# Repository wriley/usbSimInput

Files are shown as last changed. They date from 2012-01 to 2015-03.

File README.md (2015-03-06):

# usbSimInput

This project is a 128 button USB HID joystick based on an open source USB game controller adapter by Raphaël Assénat.
http://www.raphnet-tech.com/products/nes2usb/

I use it to interface a lot of switches to a flight simulator but you could use it for anything that requires a lot of buttons.

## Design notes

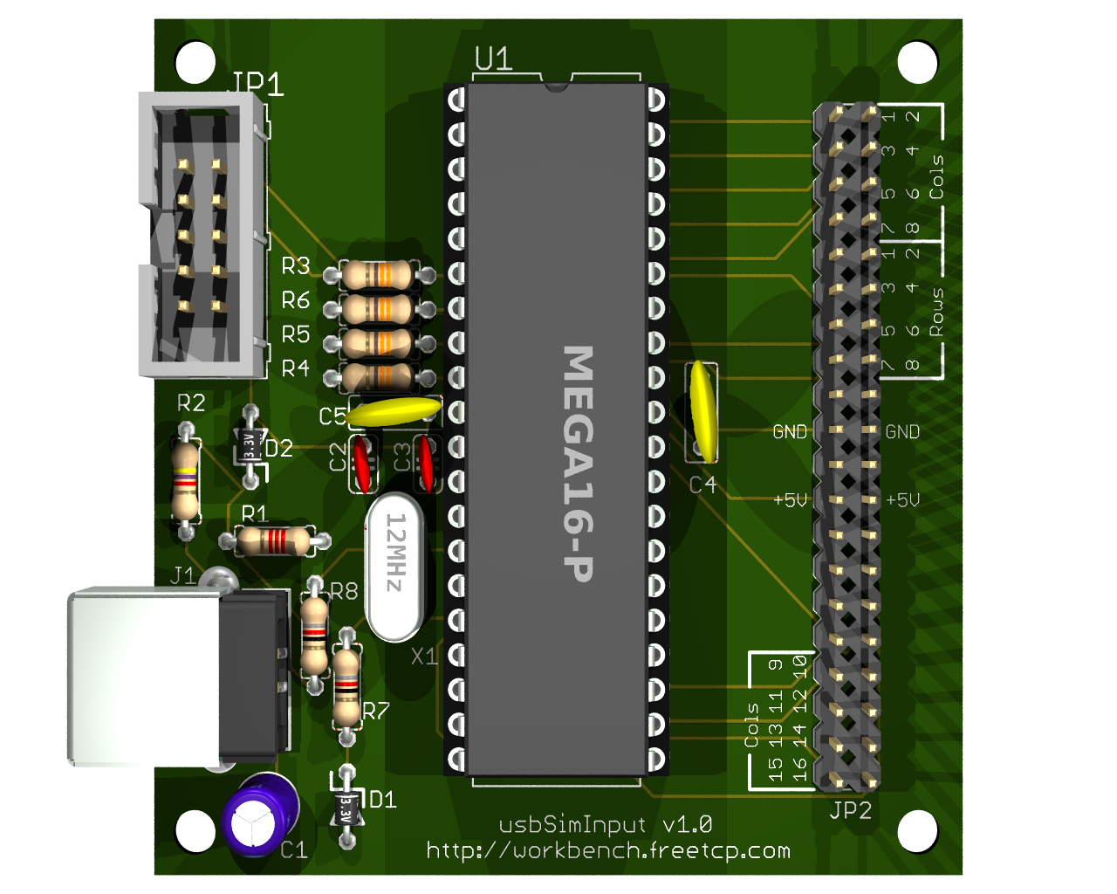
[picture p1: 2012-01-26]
pcb/usbSimInput.bmp

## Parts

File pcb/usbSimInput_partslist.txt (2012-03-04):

Partlist

Exported from usbSimInput.sch at 3/3/2012 2:18:12 PM

EAGLE Version 6.1.0 Copyright (c) 1988-2012 CadSoft

Assembly variant: 

Part     Value          Device          Package      Library  Sheet

C1       10uF           CPOL-USE2.5-5   E2,5-5       rcl      1
C2       15pF           C-US025-024X044 C025-024X044 rcl      1
C3       15pF           C-US025-024X044 C025-024X044 rcl      1
C4       0.1uF          C-US050-025X075 C050-025X075 rcl      1
C5       0.1uF          C-US050-025X075 C050-025X075 rcl      1
D1       3.3V           ZENER-DIODEZD-5 ZDIO-5       diode    1
D2       3.3V           ZENER-DIODEZD-5 ZDIO-5       diode    1
J1                      PN61729-S       PN61729-S    con-berg 1
JP1                     ML10            ML10         con-ml   1
JP2                     MA20-2          MA20-2       con-lstb 1
R1       2K2            R-US_0207/7     0207/7       resistor 1
R2       4K7            R-US_0207/7     0207/7       resistor 1
R3       330            R-US_0207/7     0207/7       resistor 1
R4       330            R-US_0207/7     0207/7       resistor 1
R5       330            R-US_0207/7     0207/7       resistor 1
R6       330            R-US_0207/7     0207/7       resistor 1
R7       82             R-US_0207/7     0207/7       resistor 1
R8       82             R-US_0207/7     0207/7       resistor 1
U1       MEGA16-P       MEGA16-P        DIL40        atmel    1
X1       12MHz          CRYSTALHC49U-V  HC49U-V      crystal  1

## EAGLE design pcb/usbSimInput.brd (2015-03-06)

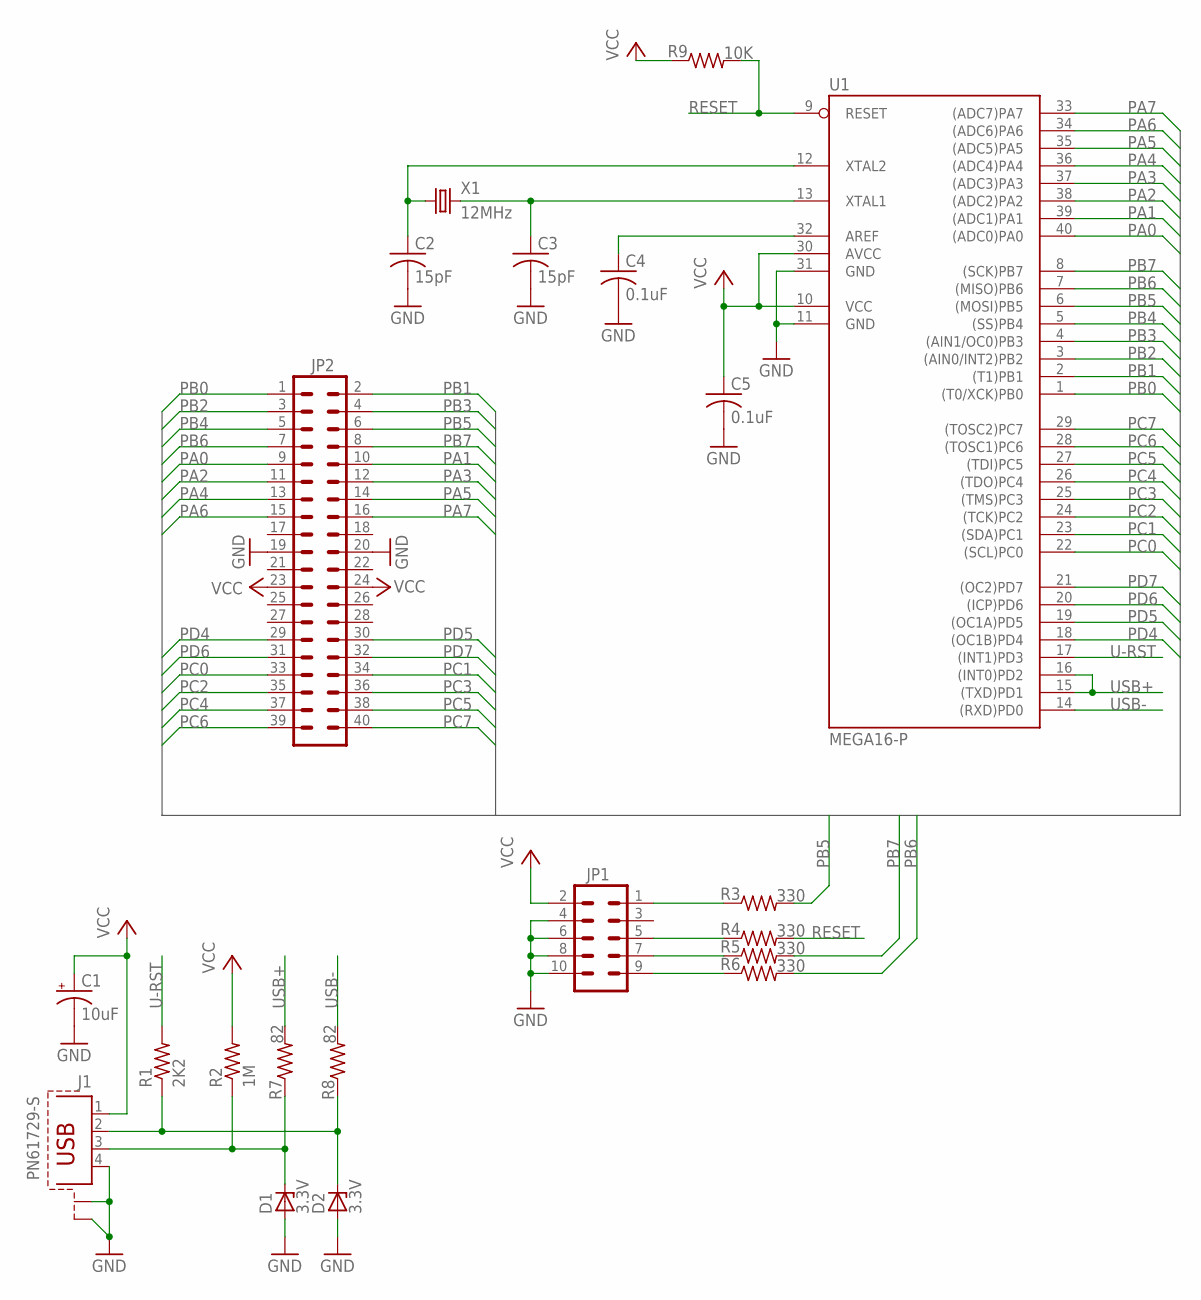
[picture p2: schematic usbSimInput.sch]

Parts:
C1: 10uF; E2,5-5
C2, C3: 15pF; C025-024X044
C4, C5: 0.1uF; C050-025X075
D1, D2: 3.3V; ZDIO-5
J1: PN61729-S
JP1: ML10
JP2: MA20-2
R1: 2K2; 0207/7
R2: 1M; 0207/7
R3, R4, R5, R6: 330; 0207/7
R7, R8: 82; 0207/7
R9: 10K; 0207/7
U1: MEGA16-P; DIL40
X1: 12MHz; HC49U-V

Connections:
GND: C1.-, C2.2, C3.2, C4.2, C5.2, D1.A, D2.A, J1.4, J1.S1, J1.S2, JP1.4, JP1.6, JP1.8, JP1.10, JP2.19, JP2.20, U1.11 (GND), U1.31 (GND)
unnamed: JP1.1, R3.1
unnamed: JP1.5, R4.1
unnamed: JP1.7, R5.1
unnamed: JP1.9, R6.1
unnamed: C3.1, U1.13 (XTAL1), X1.2
unnamed: C2.1, U1.12 (XTAL2), X1.1
unnamed: D2.C, J1.2, R1.1, R8.1
unnamed: C4.1, U1.32 (AREF)
unnamed: D1.C, J1.3, R2.1, R7.1
PA0: JP2.9, U1.40 ((ADC0)PA0)
PA1: JP2.10, U1.39 ((ADC1)PA1)
PA2: JP2.11, U1.38 ((ADC2)PA2)
PA3: JP2.12, U1.37 ((ADC3)PA3)
PA4: JP2.13, U1.36 ((ADC4)PA4)
PA5: JP2.14, U1.35 ((ADC5)PA5)
PA6: JP2.15, U1.34 ((ADC6)PA6)
PA7: JP2.16, U1.33 ((ADC7)PA7)
PB0: JP2.1, U1.1 ((T0/XCK)PB0)
PB1: JP2.2, U1.2 ((T1)PB1)
PB2: JP2.3, U1.3 ((AIN0/INT2)PB2)
PB3: JP2.4, U1.4 ((AIN1/OC0)PB3)
PB4: JP2.5, U1.5 ((SS)PB4)
PB5: JP2.6, R3.2, U1.6 ((MOSI)PB5)
PB6: JP2.7, R6.2, U1.7 ((MISO)PB6)
PB7: JP2.8, R5.2, U1.8 ((SCK)PB7)
PC0: JP2.33, U1.22 ((SCL)PC0)
PC1: JP2.34, U1.23 ((SDA)PC1)
PC2: JP2.35, U1.24 ((TCK)PC2)
PC3: JP2.36, U1.25 ((TMS)PC3)
PC4: JP2.37, U1.26 ((TDO)PC4)
PC5: JP2.38, U1.27 ((TDI)PC5)
PC6: JP2.39, U1.28 ((TOSC1)PC6)
PC7: JP2.40, U1.29 ((TOSC2)PC7)
PD4: JP2.29, U1.18 ((OC1B)PD4)
PD5: JP2.30, U1.19 ((OC1A)PD5)
PD6: JP2.31, U1.20 ((ICP)PD6)
PD7: JP2.32, U1.21 ((OC2)PD7)
RESET: R4.2, R9.2, U1.9 (RESET)
U-RST: R1.2, U1.17 ((INT1)PD3)
USB+: R7.2, U1.15 ((TXD)PD1), U1.16 ((INT0)PD2)
USB-: R8.2, U1.14 ((RXD)PD0)
VCC: C1.+, C5.1, J1.1, JP1.2, JP2.23, JP2.24, R2.2, R9.1, U1.10 (VCC), U1.30 (AVCC)

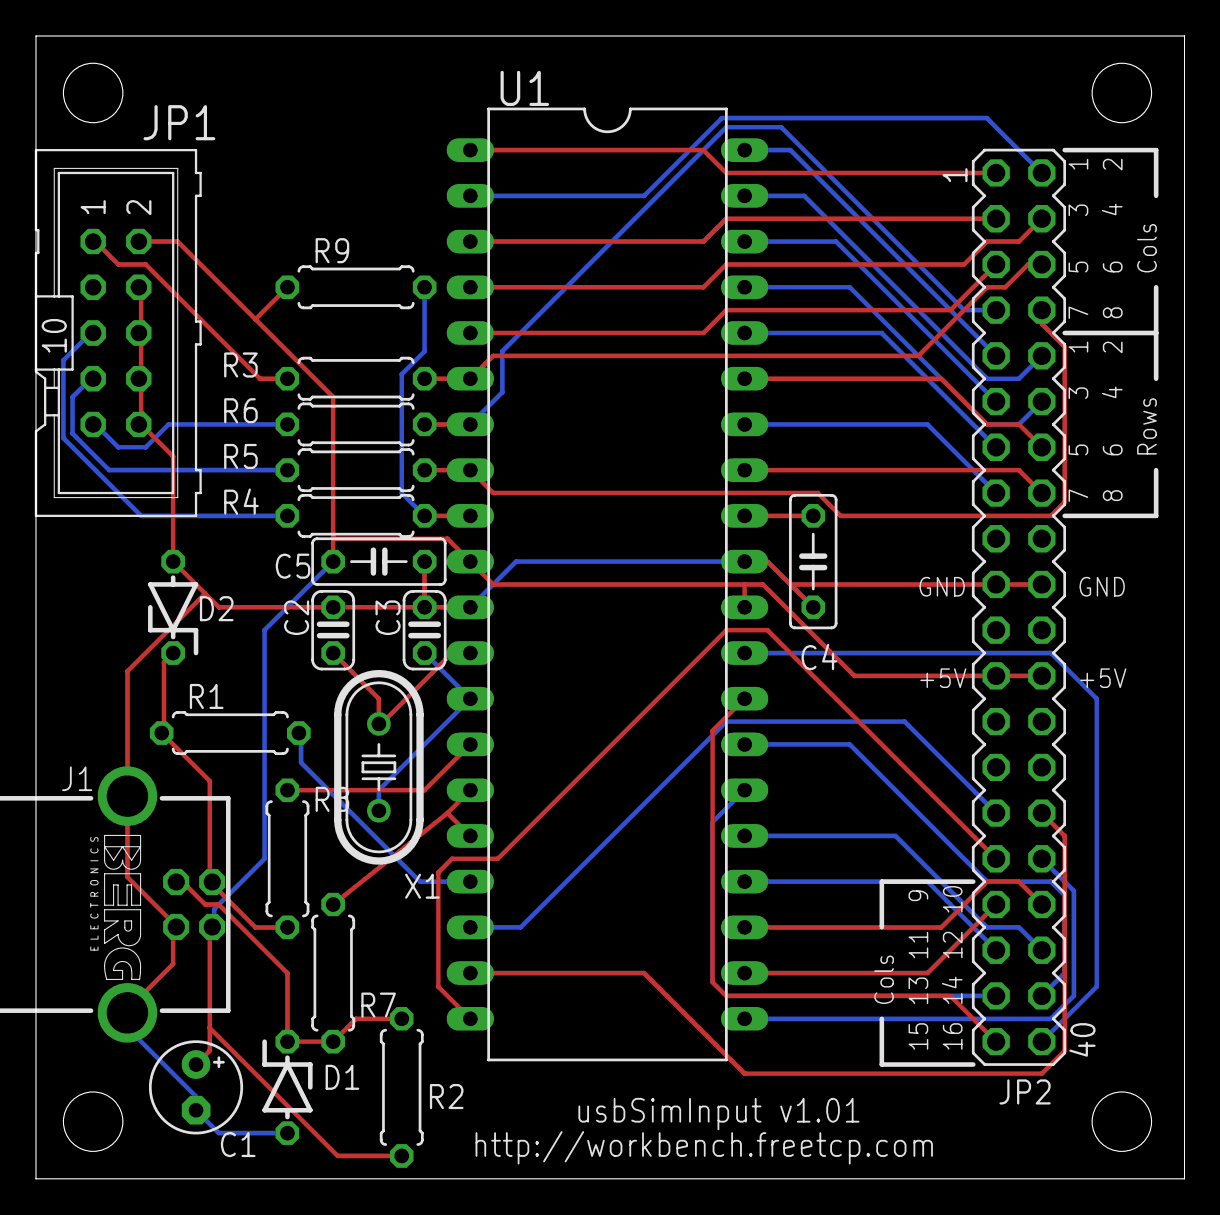
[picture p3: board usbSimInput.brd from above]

Board: 2 copper layers, 63.8 x 63.5 mm, 25 parts (0 on the bottom side), 43 nets.

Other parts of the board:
U$1, U$2, U$3, U$4: STAND-OFF

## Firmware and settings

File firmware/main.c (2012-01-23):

/* Name: main.c
 * Project: usbSimInput - 128 button HID joystick
 * Author: William Riley
 * Creation Date: 2012-01-23
 * Tabsize: 4
 * Copyright: (c) 2012 by William Riley
 * License: GNU GPL v2 (see License.txt)
 */

#include <avr/io.h>
#include <avr/wdt.h>
#include <avr/interrupt.h>
#include <util/delay.h>

#include <avr/pgmspace.h>
#include "usbdrv.h"
#include "oddebug.h"

/* ------------------------------------------------------------------------- */
/* ----------------------------- USB interface ----------------------------- */
/* ------------------------------------------------------------------------- */

PROGMEM char usbHidReportDescriptor[28] = { /* USB report descriptor, size must match usbconfig.h */
    0x05, 0x01,                    // USAGE_PAGE (Generic Desktop)
    0x09, 0x04,                    // USAGE (Joystick)
    0xa1, 0x01,                    // COLLECTION (Application)
    0x09, 0x04,                    //   USAGE (Joystick)
    0xa1, 0x00,                    //   COLLECTION (Physical)
    0x05, 0x09,                    //     USAGE_PAGE (Button)
    0x19, 0x01,                    //     USAGE_MINIMUM (Button 1)
    0x29, 0x80,                    //     USAGE_MAXIMUM (Button 128)
    0x15, 0x00,                    //     LOGICAL_MINIMUM (0)
    0x25, 0x01,                    //     LOGICAL_MAXIMUM (1)
    0x95, 0x08,                    //     REPORT_COUNT (8)
    0x75, 0x10,                    //     REPORT_SIZE (16)
    0x81, 0x02,                    //     INPUT (Data,Var,Abs)
    0xc0,                          //   END_COLLECTION
    0xc0                           // END_COLLECTION
};

int  buttonData[16];
char newDataFound;

// USB report buffer
static uchar usbReport[16];

//
// Build the USB report data
//
static uchar *usbBuildReport(void)
{
    // rebuild the report only if new data was captured
    if (newDataFound)
    {
		int  *dp = &buttonData[0];     // button data pointer
        uchar *rp = &usbReport[0];      // report buffer pointer
        int data;
        char i;

        for (i = 0; i < 16; i++)
        {
            // ensure the atomic operation
            cli();
            data = *dp++;
            sei();

            // storing data
            *rp++ = (uchar)data;
		}
		
        // reset new data flag
        newDataFound = 0;
    }

    // return the address of buffer
    return &usbReport[0];
}

//-----------------------------------------------------------------------------

//
// USB setup request processing
//
uchar usbFunctionSetup(uchar data[8])
{
    usbRequest_t *rq = (void *)data;

    if ((rq->bmRequestType & USBRQ_TYPE_MASK) == USBRQ_TYPE_CLASS)
    {
        // Return the report if host requests it without USB interrupt
        if (rq->bRequest == USBRQ_HID_GET_REPORT)
        {
            // wValue: ReportType (highbyte), ReportID (lowbyte)
            // we only have one report type, so don't look at wValue
            usbMsgPtr = usbBuildReport();
            return sizeof(usbReport);
        }
    }
    return 0;
}

//-----------------------------------------------------------------------------

//
// Check if the USB Interrupt In point buffer is empty and return
// the data buffer for the following host request via USB interrupt
//
void outSendData(void)
{
    if (usbInterruptIsReady())
    {
        // fill in the report buffer and return the
        // data pointer (Report ID is not used)
        usbSetInterrupt(usbBuildReport(), sizeof(usbReport));
    }
}

/* ------------------------------------------------------------------------- */

void inButtonInit(void)
{
	// configure PORTB and PORTC as inputs and enable pullups
	DDRB = 0x00;
	PORTB = 0xff;
	DDRC = 0x00;
	PORTC = 0xff;
	
	// configure PORTA as tristate
	DDRA = 0x00;
	PORTA = 0x00;
}

void inButtonPoll(void)
{
	for(char i = 0; i < 8; i++)
	{
		DDRA |= BIT(i);				// set to output and enable
		PORTA |= BIT(i);
		buttonData[i*2] = PINB;		// read 8 bits from PORTB
		buttonData[(i*2)+1] = PINC;	// read 8 bits from PORTC
		PORTA &= ~(BIT(i));			// disable and set to tristate
		DDRA &= ~(BIT(i));
	}
	
	newDataFound = 1;
}

void wdInit(void)
{
#if defined(__IOM16_H) || defined(__IOM32_H)
    WDTCR = (7 << WDP0) | (1 << WDE);
#else
    WDTCR = (1 << WDCE) | (1 << WDE);
#endif
    WDTCR = (7 << WDP0) | (1 << WDE);
}

void wdReset(void)
{
    wdt_reset();
}

int main(void)
{
    wdInit();                       // initialize watchdog timer
    usbInit();                      // initialize USB driver
    inButtonInit();                 // initialize inputs
    usbDeviceConnect();             // connect USB device to USB bus
    sei();                          // required by USB driver and some interfaces

    while (1)
    {
        wdReset();                  // reset watchdog timer
        inButtonPoll();             // poll for input data
        outSendData();              // prepare data for USB Interrupt In endpoint
        usbPoll();                  // process USB requests
	}
}

/* ------------------------------------------------------------------------- */

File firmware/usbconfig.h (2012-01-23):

/* Name: usbconfig.h
 * Project: V-USB, virtual USB port for Atmel's(r) AVR(r) microcontrollers
 * Author: Christian Starkjohann
 * Creation Date: 2005-04-01
 * Tabsize: 4
 * Copyright: (c) 2005 by OBJECTIVE DEVELOPMENT Software GmbH
 * License: GNU GPL v2 (see License.txt), GNU GPL v3 or proprietary (CommercialLicense.txt)
 * This Revision: $Id$
 */

#ifndef __usbconfig_h_included__
#define __usbconfig_h_included__

/*
General Description:
This file is an example configuration (with inline documentation) for the USB
driver. It configures V-USB for USB D+ connected to Port D bit 2 (which is
also hardware interrupt 0 on many devices) and USB D- to Port D bit 4. You may
wire the lines to any other port, as long as D+ is also wired to INT0 (or any
other hardware interrupt, as long as it is the highest level interrupt, see
section at the end of this file).
+ To create your own usbconfig.h file, copy this file to your project's
+ firmware source directory) and rename it to "usbconfig.h".
+ Then edit it accordingly.
*/

/* ---------------------------- Hardware Config ---------------------------- */

#define USB_CFG_IOPORTNAME      D
/* This is the port where the USB bus is connected. When you configure it to
 * "B", the registers PORTB, PINB and DDRB will be used.
 */
#define USB_CFG_DMINUS_BIT      0
/* This is the bit number in USB_CFG_IOPORT where the USB D- line is connected.
 * This may be any bit in the port.
 */
#define USB_CFG_DPLUS_BIT       1
/* This is the bit number in USB_CFG_IOPORT where the USB D+ line is connected.
 * This may be any bit in the port. Please note that D+ must also be connected
 * to interrupt pin INT0! [You can also use other interrupts, see section
 * "Optional MCU Description" below, or you can connect D- to the interrupt, as
 * it is required if you use the USB_COUNT_SOF feature. If you use D- for the
 * interrupt, the USB interrupt will also be triggered at Start-Of-Frame
 * markers every millisecond.]
 */
#define USB_CFG_CLOCK_KHZ       (F_CPU/1000)
/* Clock rate of the AVR in kHz. Legal values are 12000, 12800, 15000, 16000,
 * 16500, 18000 and 20000. The 12.8 MHz and 16.5 MHz versions of the code
 * require no crystal, they tolerate +/- 1% deviation from the nominal
 * frequency. All other rates require a precision of 2000 ppm and thus a
 * crystal!
 * Since F_CPU should be defined to your actual clock rate anyway, you should
 * not need to modify this setting.
 */
#define USB_CFG_CHECK_CRC       0
/* Define this to 1 if you want that the driver checks integrity of incoming
 * data packets (CRC checks). CRC checks cost quite a bit of code size and are
 * currently only available for 18 MHz crystal clock. You must choose
 * USB_CFG_CLOCK_KHZ = 18000 if you enable this option.
 */

/* ----------------------- Optional Hardware Config ------------------------ */

/* #define USB_CFG_PULLUP_IOPORTNAME   D */
/* If you connect the 1.5k pullup resistor from D- to a port pin instead of
 * V+, you can connect and disconnect the device from firmware by calling
 * the macros usbDeviceConnect() and usbDeviceDisconnect() (see usbdrv.h).
 * This constant defines the port on which the pullup resistor is connected.
 */
/* #define USB_CFG_PULLUP_BIT          4 */
/* This constant defines the bit number in USB_CFG_PULLUP_IOPORT (defined
 * above) where the 1.5k pullup resistor is connected. See description
 * above for details.
 */

/* --------------------------- Functional Range ---------------------------- */
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

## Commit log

2011-04-29 started schematic
    [usbSimInput.sch]
2011-04-29 first stab at completed schematic and a 2 layer board
    [usbSimInput.brd, usbSimInput.sch]
2011-05-01 usbSimInput.sch: changed to ExpressPCB
    [usbSimInput.brd, usbSimInput.sch]
2011-05-01 usbSimInput.sch: started button connections
    [usbSimInput.sch]
2011-05-02 usbSimInput.sch: finished button connections
    [usbSimInput.sch]
2011-05-02 usbSimInput.pcb: started board layout
2011-06-01 moved input connections to separate board
    [usbSimInput.sch, usbSimInput_Breakout_Board.sch]
2011-06-01 usbSimInput.sch: changed ISP connector from 6-pin to 10-pin usbSimInput.pcb: started layout
    [usbSimInput.sch]
2011-06-03 pcb layout work changed from 34-pin connector to 3 8-pin connectors
    [usbSimInput.sch, usbSimInput_Breakout_Board.sch]
2011-06-10 usbSimInput.sch: changed from 10-pin to 6-pin ISP connector, added 4-pin header for unused MCU pins usbSimInput.pcb: finished layout, needs testing
    [usbSimInput.sch]
2011-06-10 usbSimInput.sch: changed PORTC resistors to resistor network usbSimInput.pcb: minor trace tweaks, SIP resistor network for PORTC
    [usbSimInput.sch]
2012-01-23 Changed from ExpressPCB to Eagle
    [usbSimInput.brd, usbSimInput.sch, usbSimInput_Breakout_Board.sch]
2012-01-24 Layout tweaks for Seeed DRU
    [usbSimInput.brd]
2012-01-24 added gerber output (Seeed CAM)
    [usbSimInput.GBL, usbSimInput.GBO, usbSimInput.GBP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]
2012-01-25 added rows and cols to silkscreen created povray files
    [usbSimInput.brd]
2012-01-25 updated gerbers for silkscreen changes
    [usbSimInput.GTO]
2012-01-26 connected unused PORTD pins to header made board smaller
    [usbSimInput.GBL, usbSimInput.GBO, usbSimInput.GBP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]
2012-03-04 pcb rev to 1.01, fixed several errors and tweaked firmware enumerates
    [usbSimInput.brd, usbSimInput.sch]
2012-03-06 firmware working as 64-button HID joystick
2012-03-07 Mostly working 128 button firmware. Buttons sometime "stick" on
2012-03-09 fixed AREF->VCC error
    [usbSimInput.brd, usbSimInput.sch]
2012-03-09 Working with 128 buttons
2015-03-06 updated gerbers for pcb v1.0.1
    [usbSimInput.GBL, usbSimInput.GBO, usbSimInput.GBP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]
2015-03-06 file mode fix for gerbers
    [usbSimInput.GBL, usbSimInput.GBO, usbSimInput.GBS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]
2015-03-06 edited USB connector silkscreen
    [usbSimInput.brd, usbSimInput.sch]
2015-03-06 gerbers for seeedstudio
    [usbSimInput.GBL, usbSimInput.GBP, usbSimInput.GBS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]

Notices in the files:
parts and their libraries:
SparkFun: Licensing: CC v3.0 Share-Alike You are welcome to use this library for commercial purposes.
